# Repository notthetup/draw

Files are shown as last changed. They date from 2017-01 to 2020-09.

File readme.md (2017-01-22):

Draw
===

INA260 based voltage and current __draw__ measurement board.

This is a INA260 based board for measuring voltage and current draw (with builtin shunt) and output over USB (CDC).

## Components

- [INA260](http://www.ti.com/lit/ds/symlink/ina260.pdf) - Current Sensing Amplifier With Integrated Shunt.
- [EFM32HG309](https://www.silabs.com/Support%20Documents/TechnicalDocs/EFM32HG309.pdf) - Simple Microcontroller for I2C -> USB conversion.
- [TPD4E002](http://www.ti.com/lit/ds/symlink/tpd4e002.pdf) - ESD Protection IC

## Resources

- [USB-CDC Example from SiLabs](https://github.com/SiliconLabs/Gecko_SDK/tree/master/hardware/kit/SLSTK3400A_EFM32HG/examples/usbdcdc)
- [TOMU](https://github.com/im-tomu/)
- [TOMU Example](https://github.com/im-tomu/tomu-samples/tree/master/efm32hg-blinky-usb)

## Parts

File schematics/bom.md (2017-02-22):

| Ref | Value | Type | Model | Ord/Rcd | | | | |
|-----|---|---|---|---|---|---|---|---|
| R1  | 0R | device | R_Small |  50/50  | | | | |
| R2  | 0R | device | R_Small |  50/50  | | | | |
| R3  | 0R | device | R_Small |  50/50  | | | | |
| R4  | 0R | device | R_Small |  50/50  | | | | |
| R5  | 0R | device | R_Small |  50/50  | | | | |
| R10 | 0R | device | R_Small |  50/50  | | | | |
| R12 | 0R | device | R_Small |  50/50  | | | | |
| R13 | 1K | device | R_Small |  50/50  | | | | |
| R14 | 1K | device | R_Small |  50/50  | | | | |
| R15 | 1K | device | R_Small |  50/50  | | | | |
| C3  | 1uF | device | C_Small |  60/60  | | | | |
| C2  | 1uF | device | C_Small |  60/60  | | | | |
| C5  | 1uF | device | C_Small |  60/60  | | | | |
| R6  | 15R | device | R_Small |  50/50  | | | | |
| R7  | 15R | device | R_Small |  50/50  | | | | |
| C1  | 4.7uF | device | C_Small |  10/10  | | | | |
| C1  | 4.7uF | device | C_Small |  10/10  | | | | |
| C4  | 0.1uF | device | C_Small |  50/50  | | | | |
| C6  | 1nF | device | C_Small |  50/50  | | | | |
| R8  | 100R | device | R_Small |  50/50  | | | | |
| L1  | 100R | device | Ferrite_Bead_Small |  10/10  | | | | |
| U1  | EFM32HG309 | draw | EFM32HG309 |  3/3 | | | | |
| U2  | TPD4E002 | draw | TPD4E002 |  10/10  | | | | |
| U3  | INA260 | draw | INA260 |  5/5 | | | | |
| P1  | I2C Conn | conn | CONN_01X04 | InHouse | | | | |
| P2  | UART Conn  | conn | CONN_01X04 | InHouse | | | | |
| P3  | Debug Conn | conn | CONN_01X04 | InHouse | | | | |
| P6  | Power_OUT  | conn | CONN_01X02 |  5/5 | | | | |
| P5  | Power_IN | conn | CONN_01X02 |  5/5 | | | | |
| P4  | USB_OTG | conn | USB_OTG |  5/5 | | | | |
| SW1 | SW_Push | switches | SW_Push |  10/10  | | | | |
| D1  | LED | device | LED |  10/10  | | | | |
| R9  | 0R_NP | device | R_Small |  NP | | | | |
| R11 | 0R_NP | device | R_Small |  NP | | | | |

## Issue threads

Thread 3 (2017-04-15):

Fix button footprint

notthetup, 2017-04-15:

notthetup, 2017-04-15:
Fixed in 5bd433279bf20e20d566c2123c99ecc8e3fc2ee7

notthetup, 2018-02-08:
Move to a press down button.

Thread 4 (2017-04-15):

Remove keepout for high current connectors

notthetup, 2017-04-15:
Remove heat relief and pin keepout from

1. Terminal blocks.
2. 1st 3 pins of INA260.

notthetup, 2017-04-15:
Fixed in ede29ea973610703563ed074c830674fd9ce4f38

Closed 2017-04-15.

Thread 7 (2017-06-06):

Remove mounting holes for rubber feet

notthetup, 2017-06-06:
Since the board is most commonly going to be used along with a laptop, using rubber feet glued onto the bottom makes more sense than wasting space for mounting holes.

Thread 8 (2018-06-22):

Move to a through hole USB adapter

notthetup, 2018-06-22:
Heard it on TheAmpHour “surface mount USB connector, not even once”.

https://overcast.fm/+kInNOyMM/55:00

notthetup, 2019-08-19:
Cuttent USB Connector is already through hole.

Closed 2019-08-19.

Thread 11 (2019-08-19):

Add a button to enter bootloader

notthetup, 2019-08-19:
> Bootloader is forced by a short between CAP1A (PC1) and CAP0B (PE12)

Closed 2019-08-19.

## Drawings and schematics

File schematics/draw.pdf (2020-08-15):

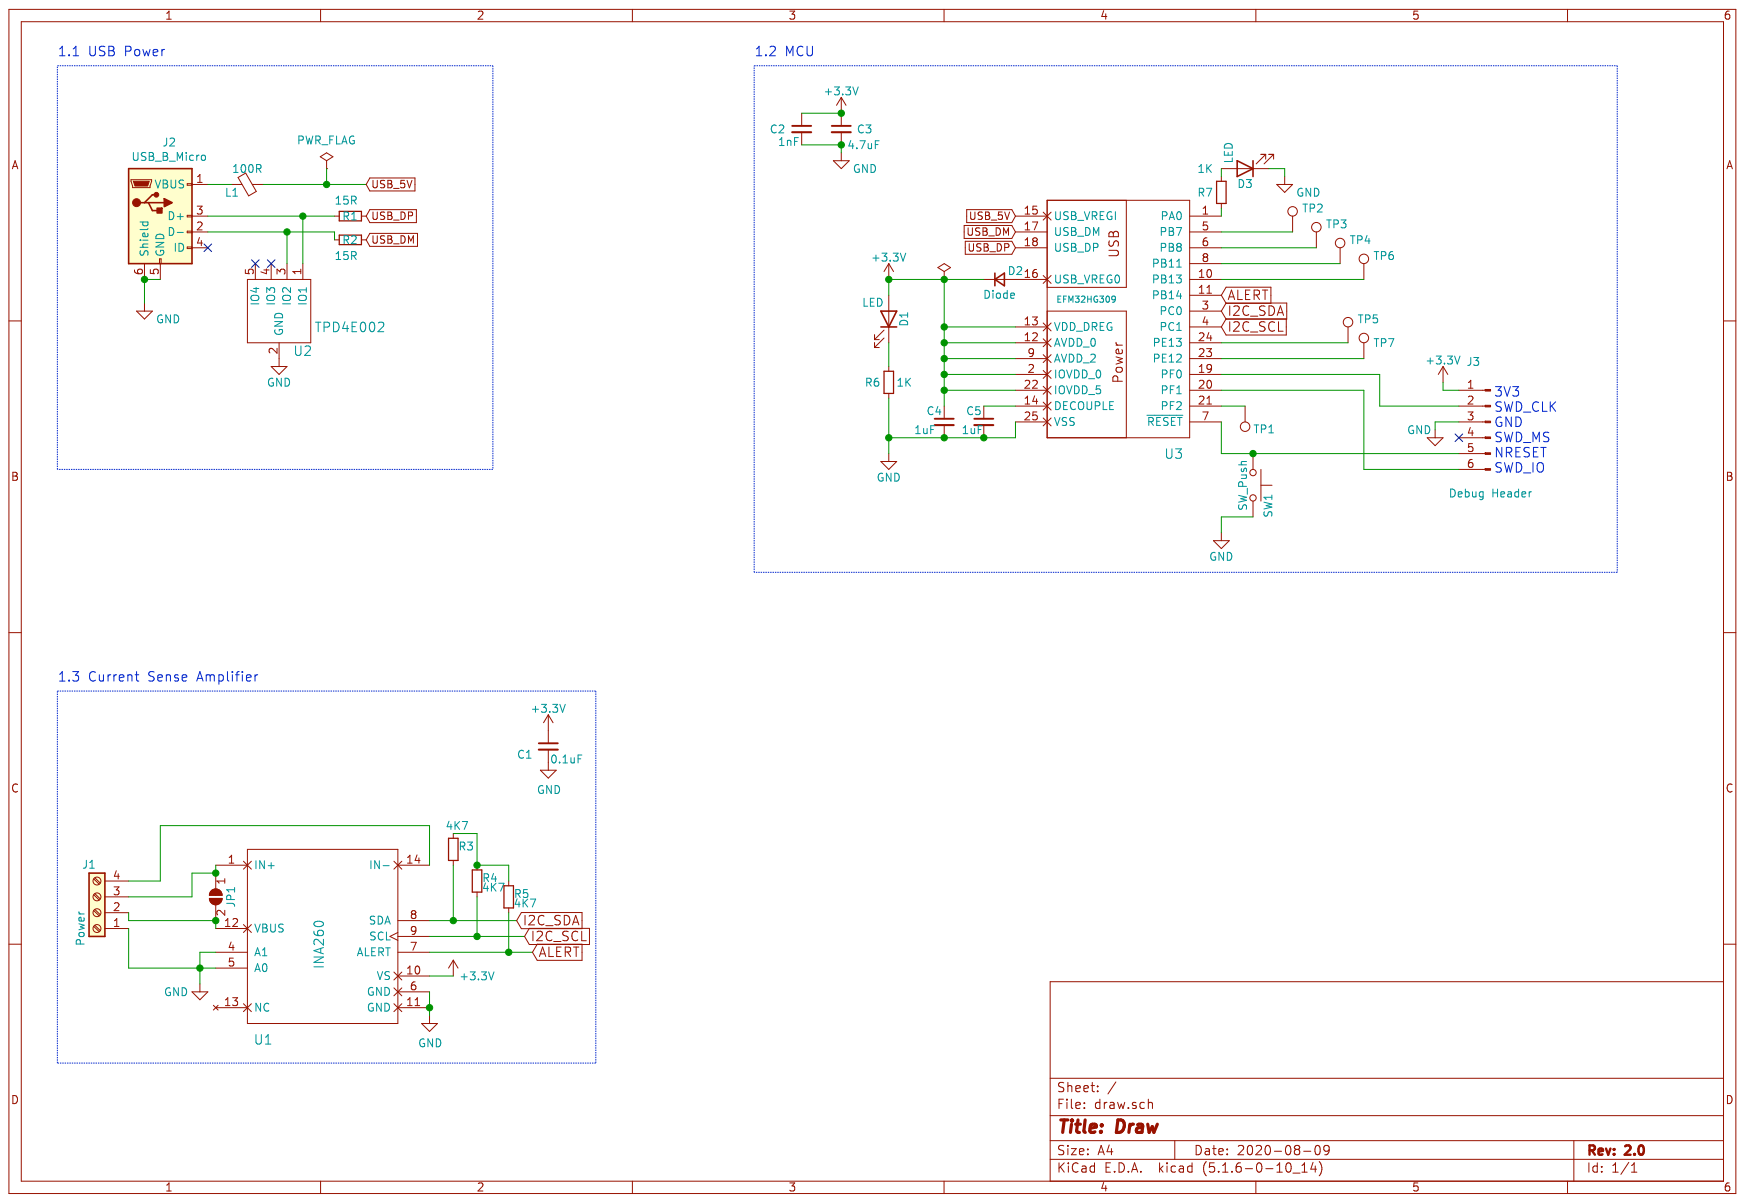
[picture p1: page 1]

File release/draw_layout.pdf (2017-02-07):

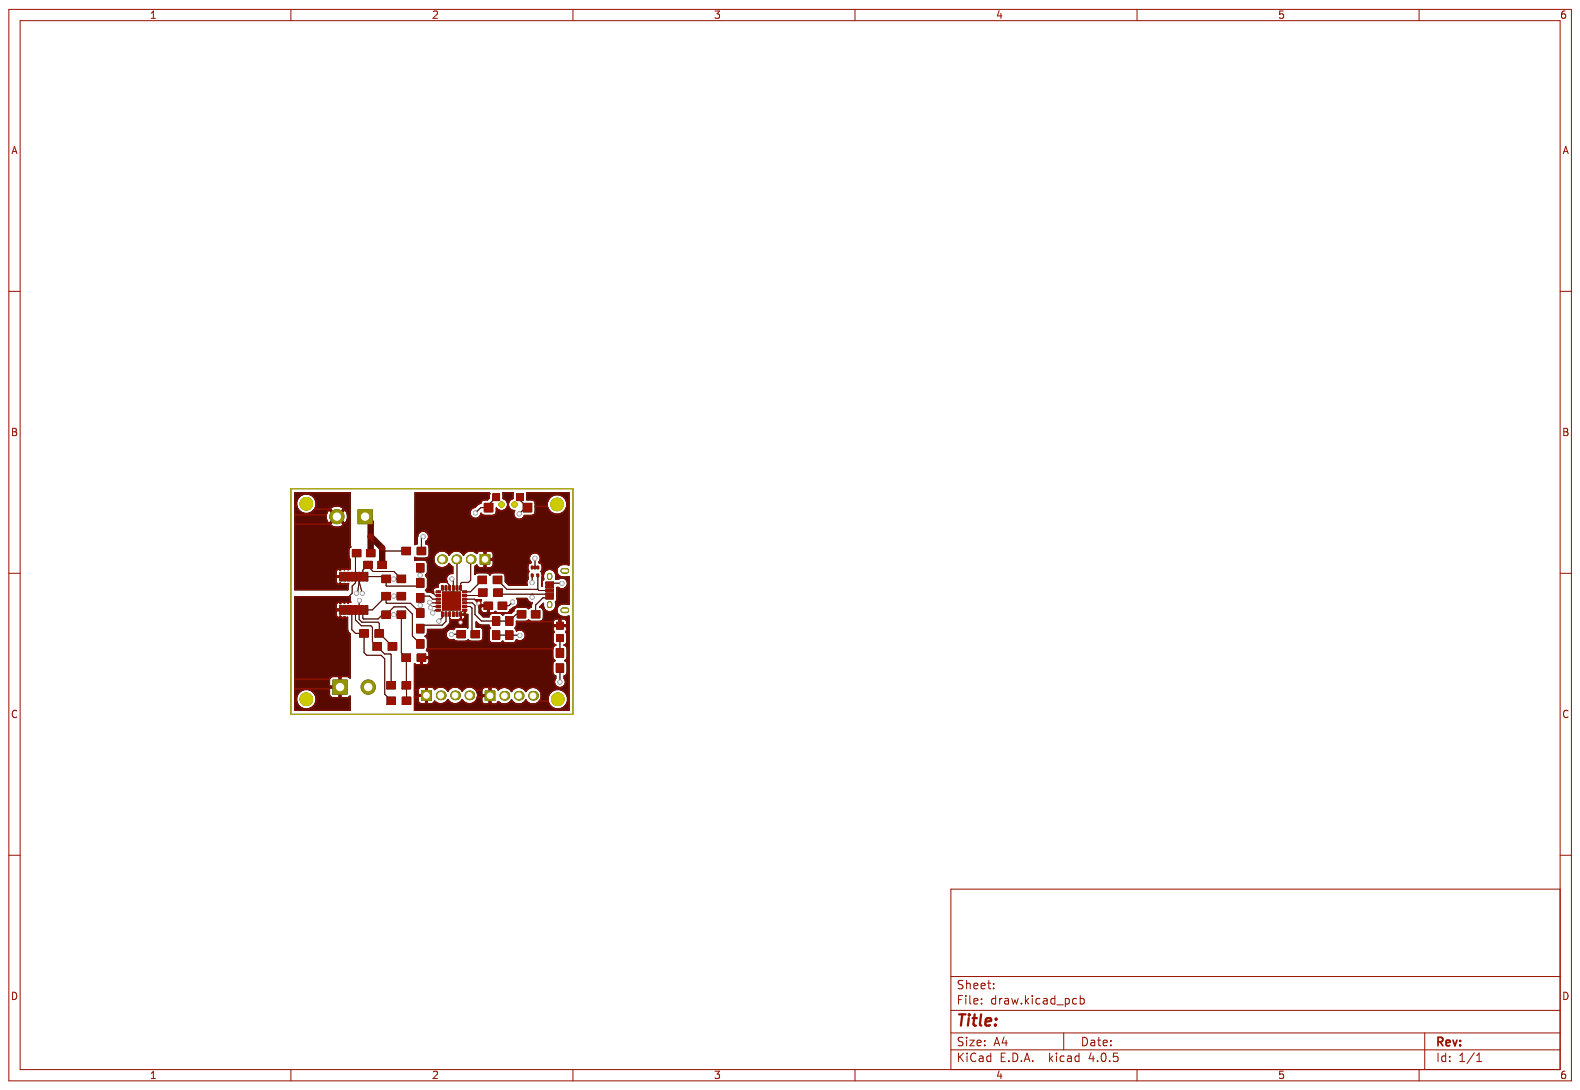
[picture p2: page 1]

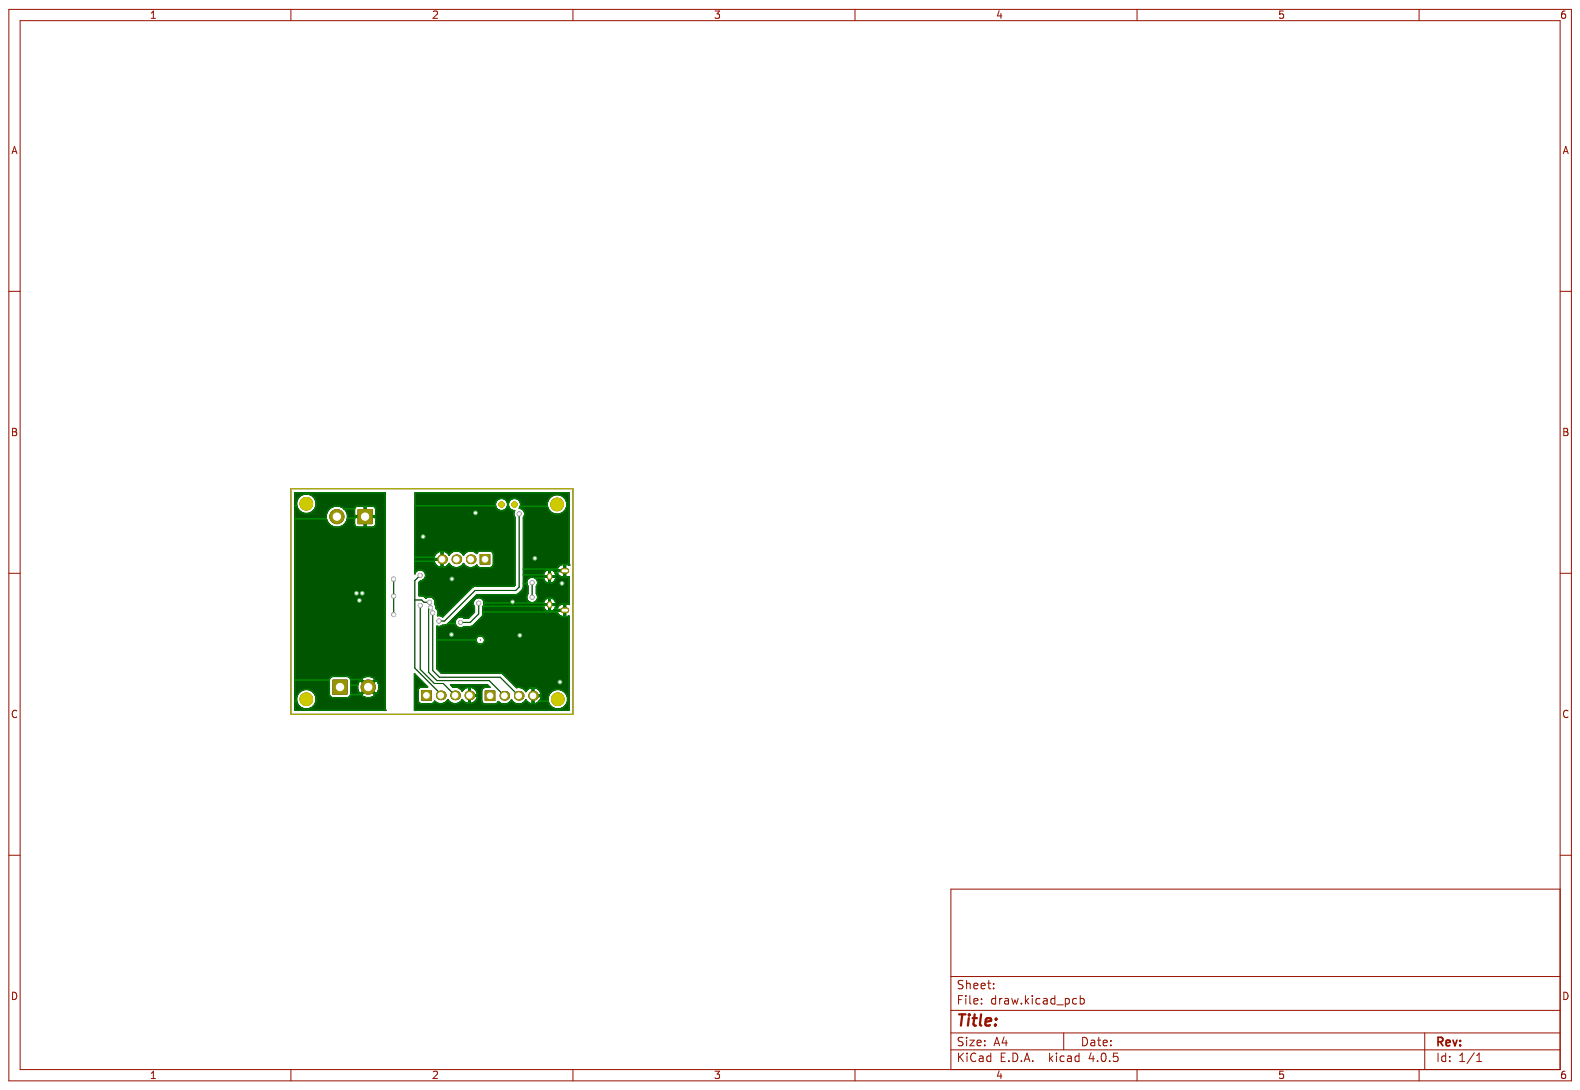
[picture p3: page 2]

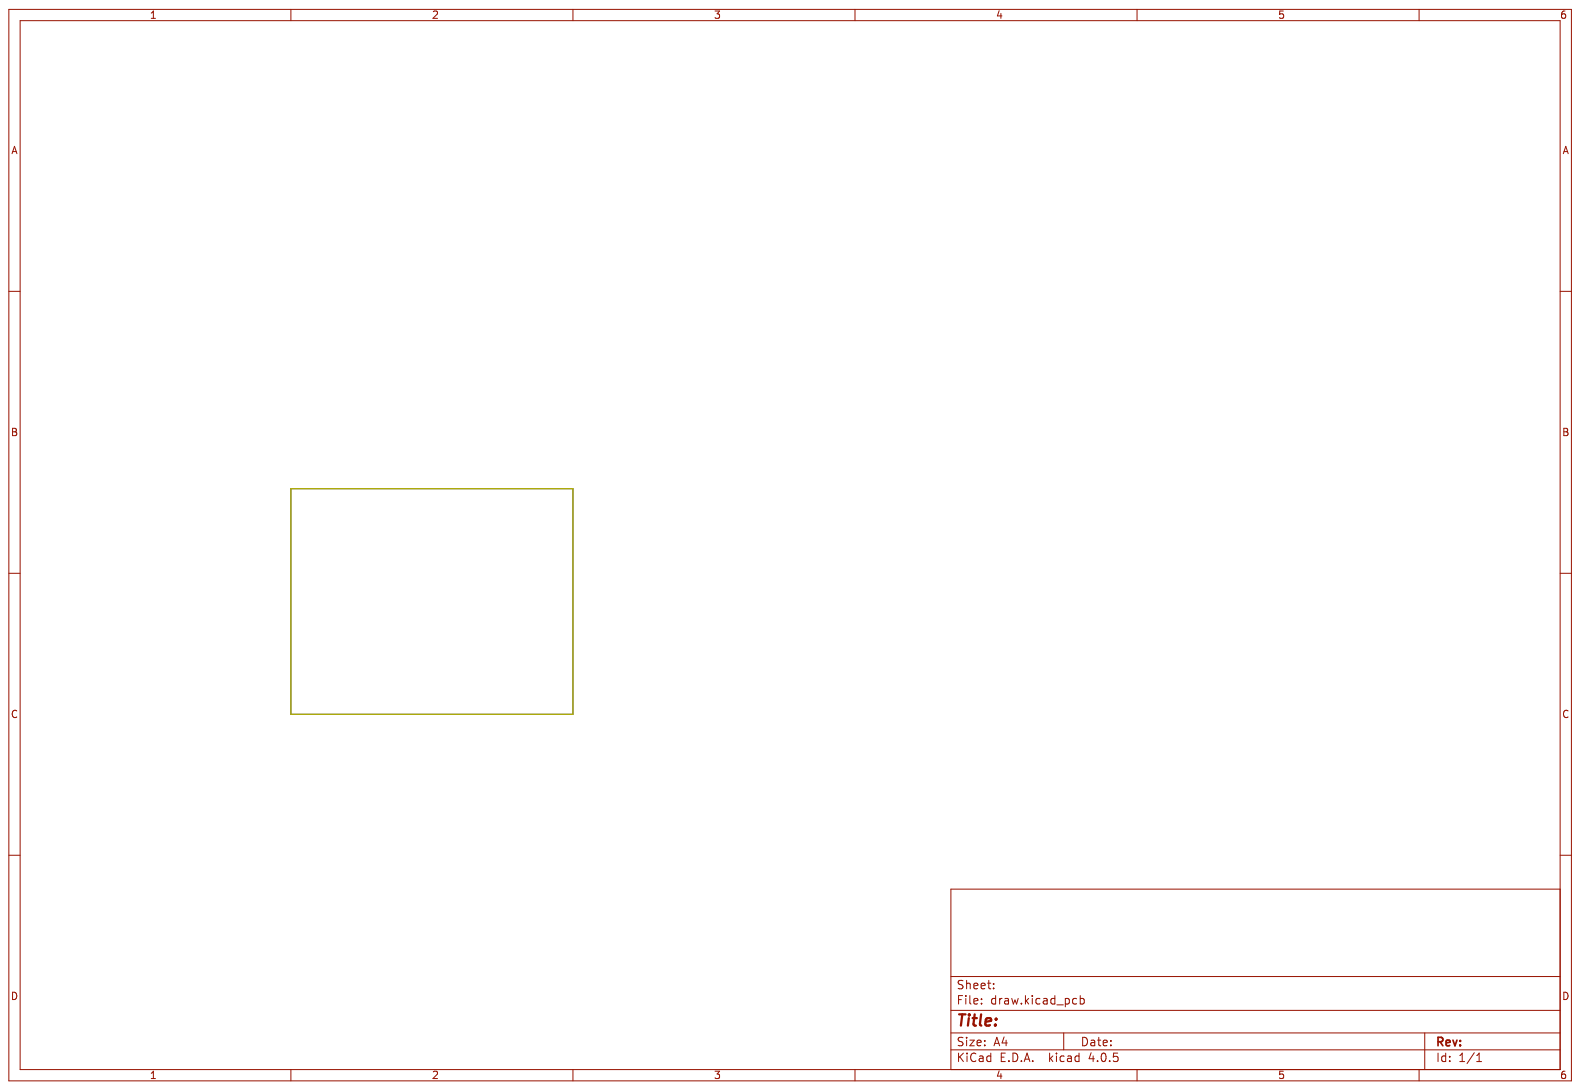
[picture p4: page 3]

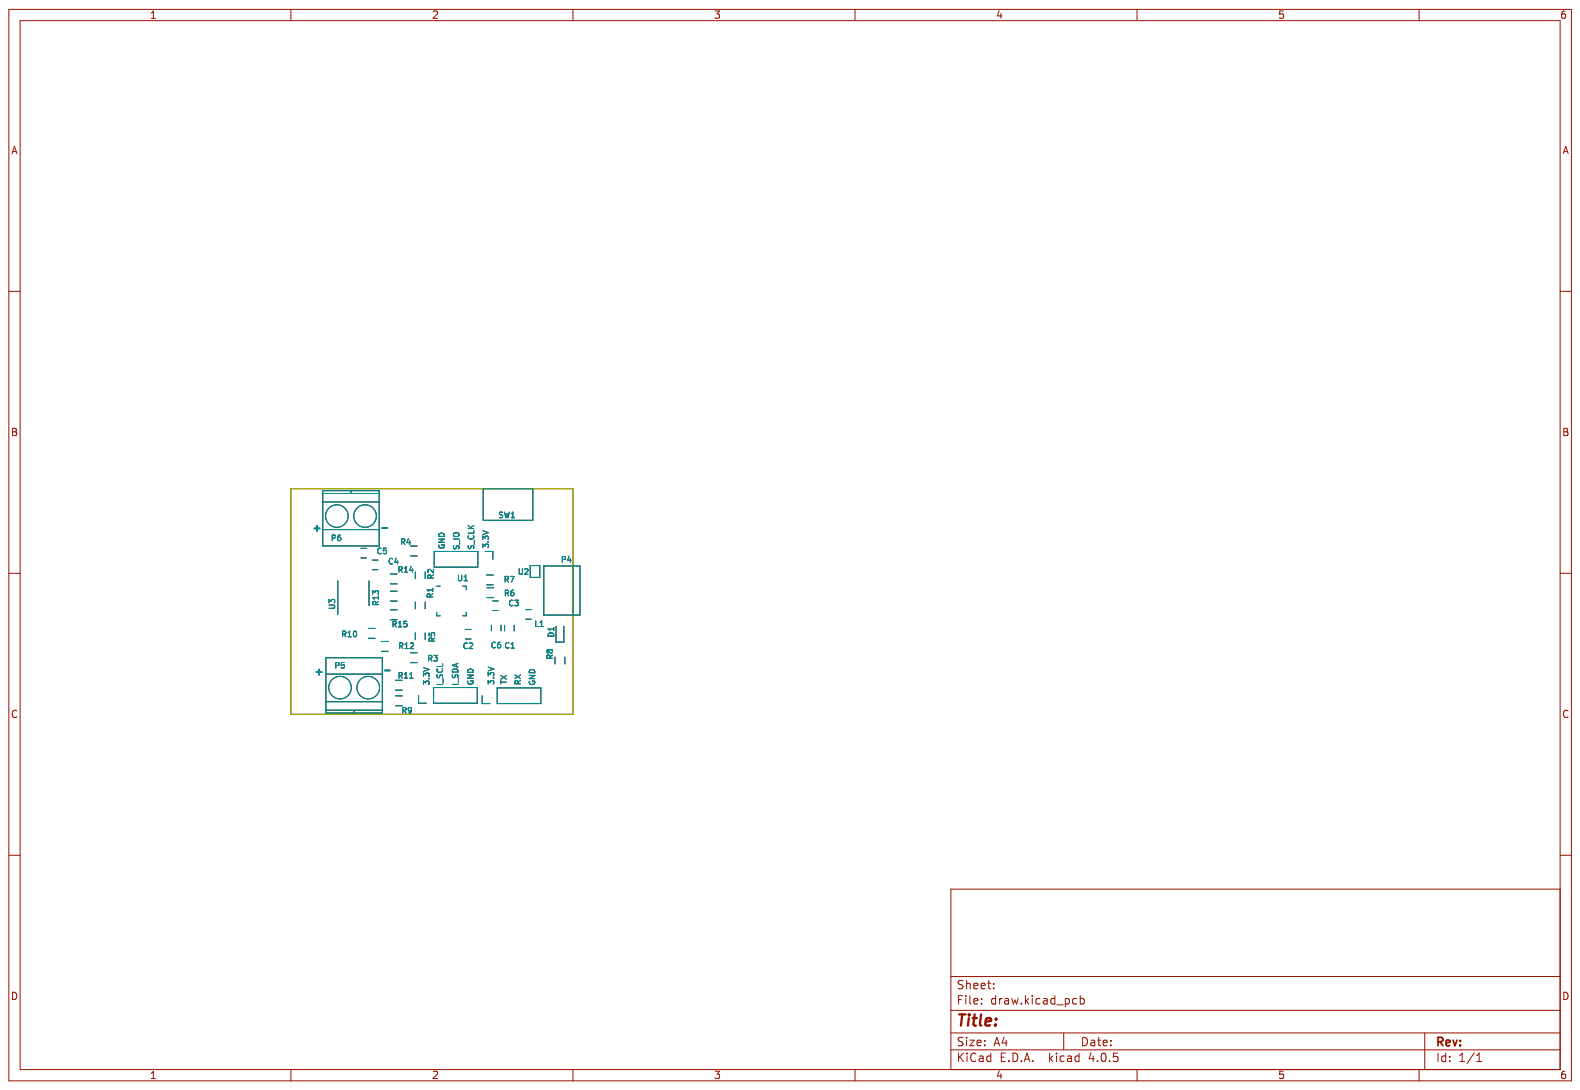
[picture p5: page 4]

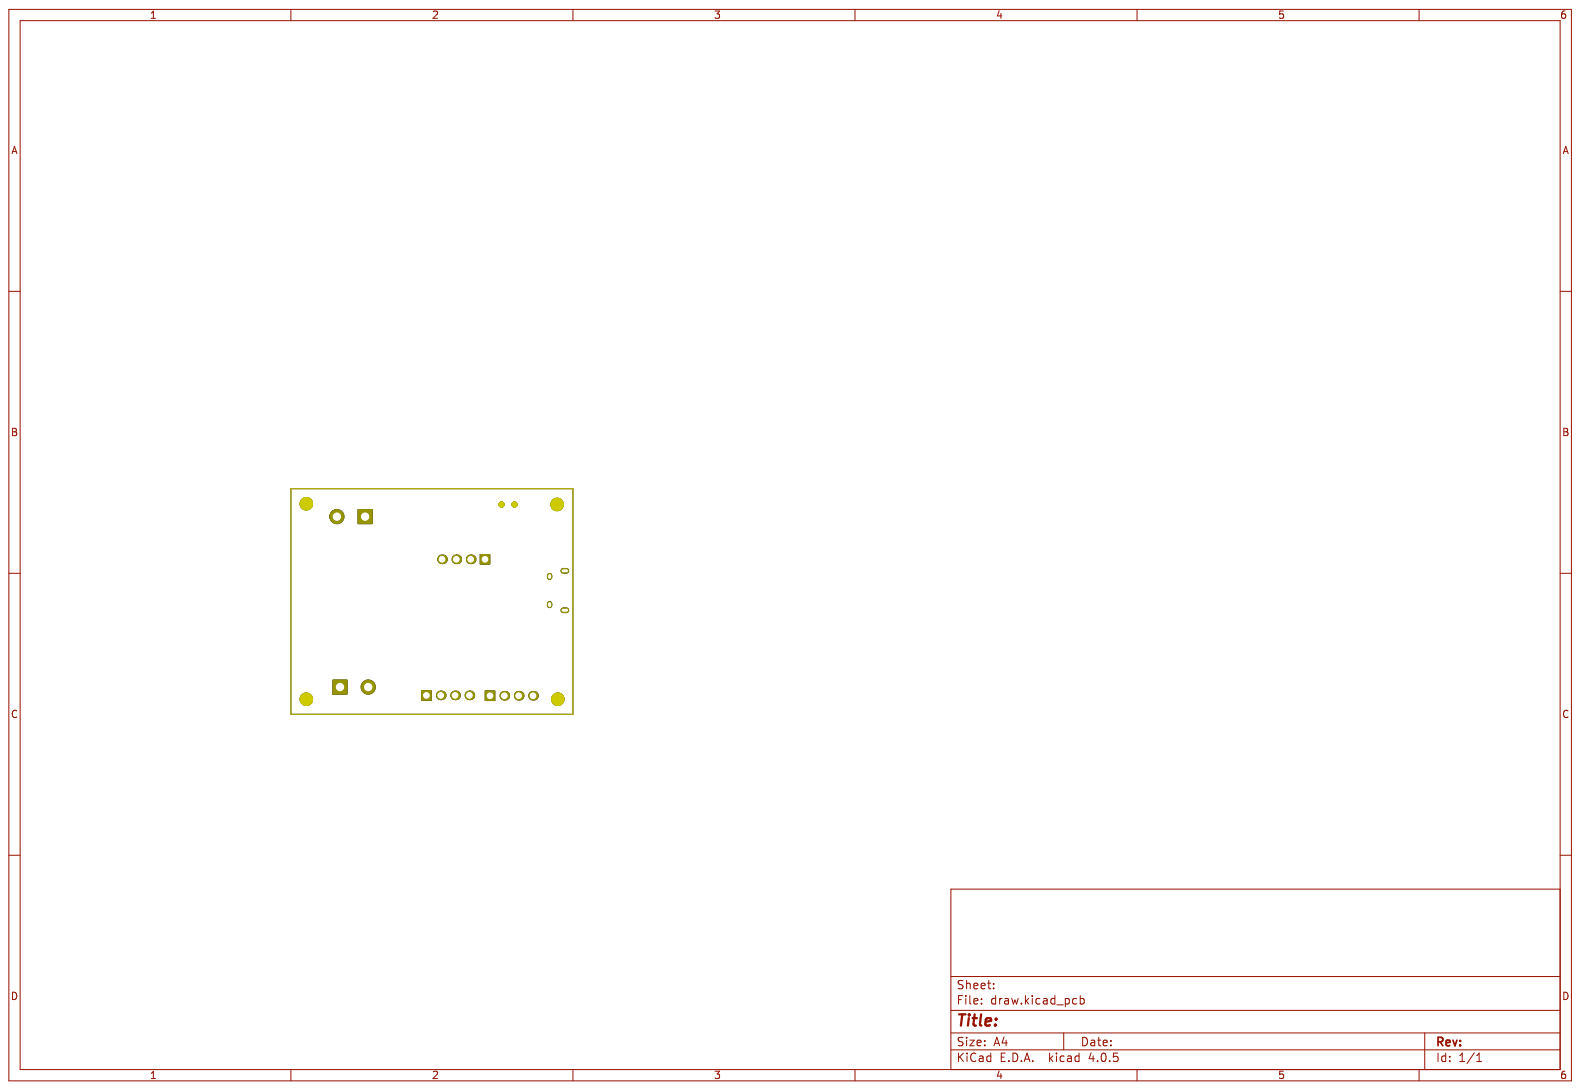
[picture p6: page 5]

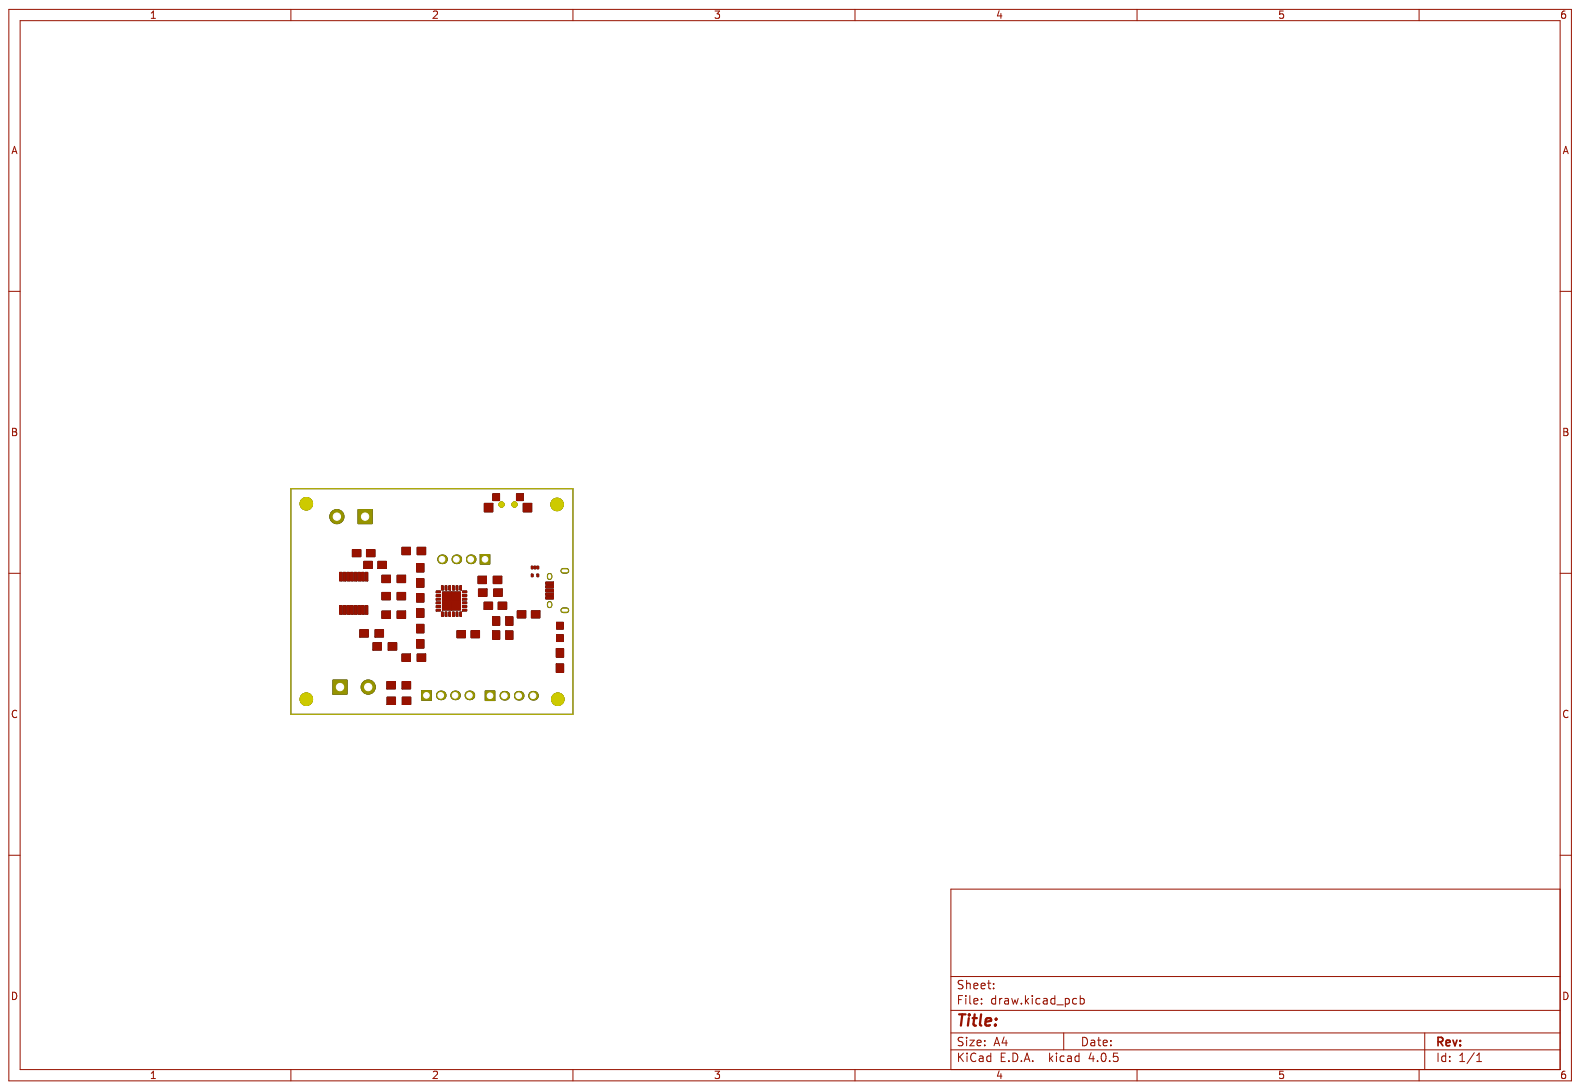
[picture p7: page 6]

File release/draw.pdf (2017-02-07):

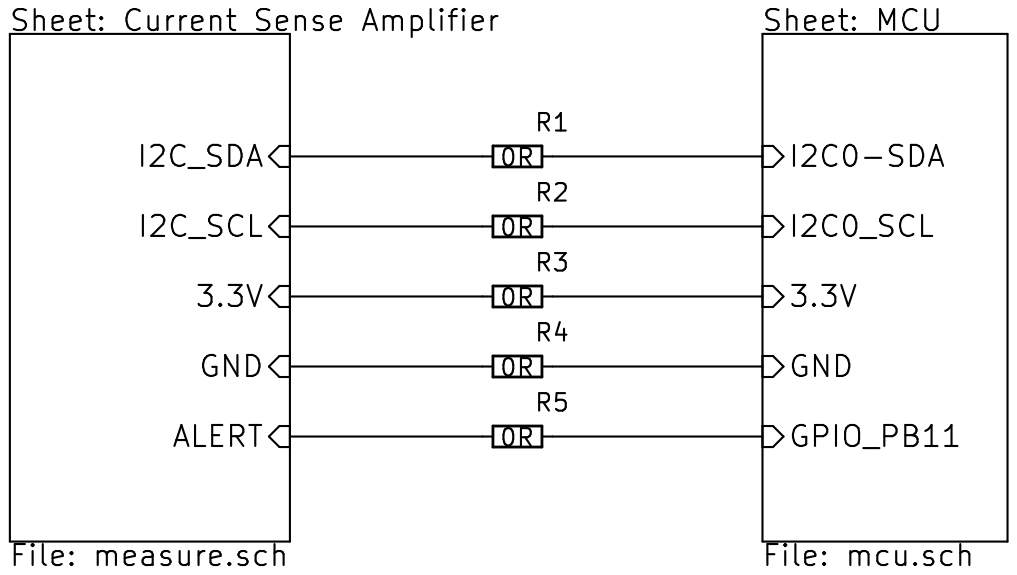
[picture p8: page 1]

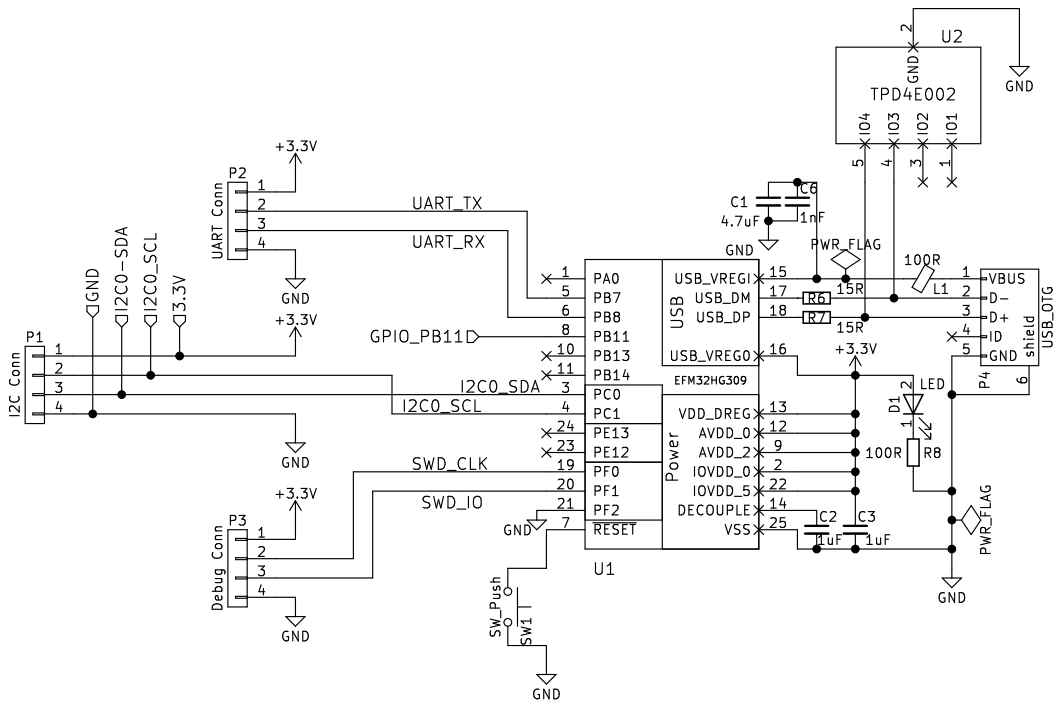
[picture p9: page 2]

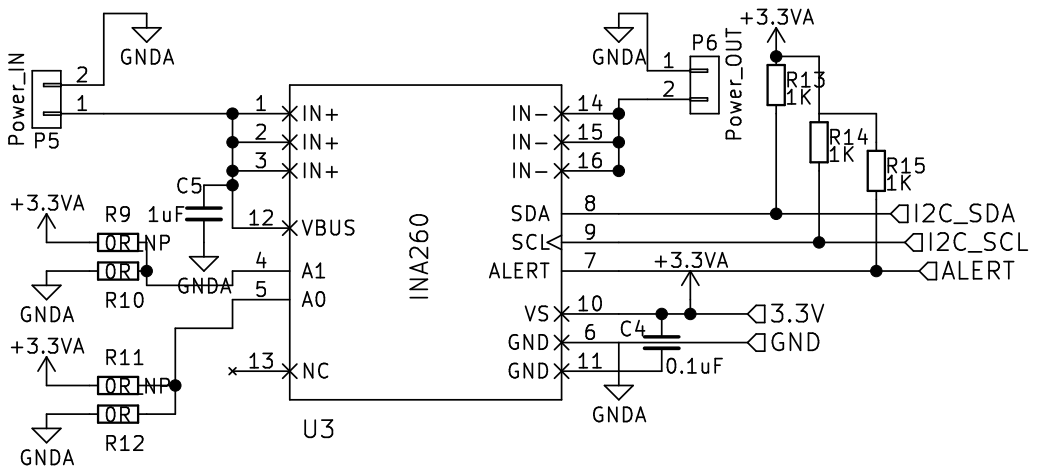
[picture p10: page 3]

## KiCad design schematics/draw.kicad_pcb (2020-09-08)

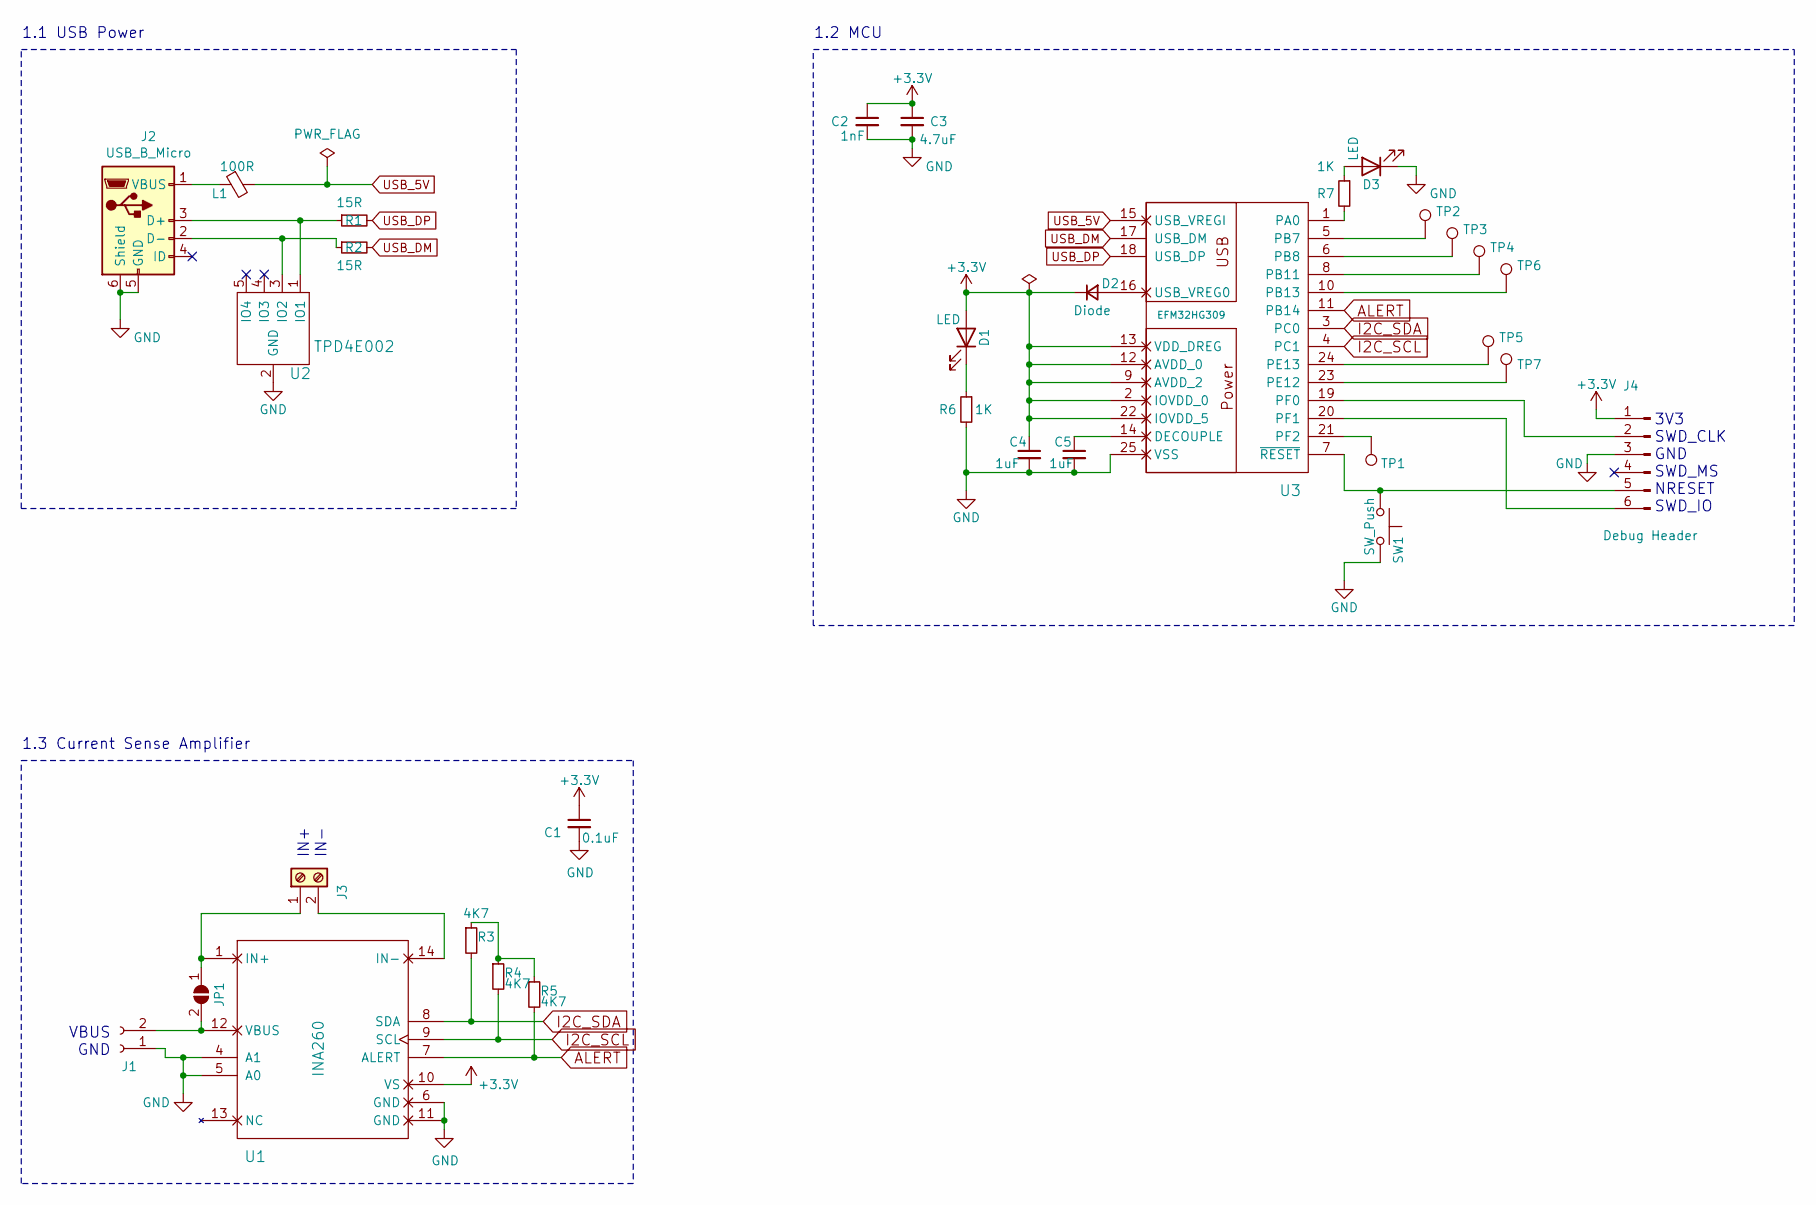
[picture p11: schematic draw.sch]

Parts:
C1: 0.1uF; C_0805_2012Metric_Pad1.15x1.40mm_HandSolder
C2: 1nF; C_0805_2012Metric_Pad1.15x1.40mm_HandSolder
C3: 4.7uF; C_0805_2012Metric_Pad1.15x1.40mm_HandSolder
C4, C5: 1uF; C_0805_2012Metric_Pad1.15x1.40mm_HandSolder
D1, D3: LED; LED_0805_2012Metric_Pad1.15x1.40mm_HandSolder
D2: Diode; D_0805_2012Metric_Pad1.15x1.40mm_HandSolder
J1: Conn_01x02_Female; PinHeader_1x02_P1.00mm_Vertical
J2: USB_B_Micro; USB_Micro-B_Amphenol_10103594-0001LF_Horizontal
J3: Screw_Terminal_01x02; TerminalBlock_MetzConnect_Type086_RT03402HBLC_1x02_P3.81mm_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
J4: Debug Header; PinSocket_1x06_P2.54mm_Vertical
JP1: Jumper; SolderJumper-2_P1.3mm_Open_RoundedPad1.0x1.5mm
L1: 100R; L_0805_2012Metric_Pad1.15x1.40mm_HandSolder
R1, R2: 15R; R_0805_2012Metric_Pad1.15x1.40mm_HandSolder
R3, R4, R5: 4K7; R_0805_2012Metric_Pad1.15x1.40mm_HandSolder
R6, R7: 1K; R_0805_2012Metric_Pad1.15x1.40mm_HandSolder
SW1: SW_Push; Tact
TP1, TP2, TP3, TP4, TP5, TP6, TP7: TestPoint; TestPoint_Pad_2.0x2.0mm
U1: INA260; TSSOP-16_4.4x5mm_P0.65mm
U2: TPD4E002; SOT-553
U3: EFM32HG309; QFN-24-1EP_5x5mm_P0.65mm_EP3.6x3.6mm

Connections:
+3V3: C1.1, C2.1, C3.1, C4.1, D1.2 (A), D2.1 (K), J4.1, U1.10 (VS), U3.2 (IOVDD_0), U3.9 (AVDD_2), U3.12 (AVDD_0), U3.13 (VDD_DREG), U3.22 (IOVDD_5)
ALERT: R5.2, U1.7 (ALERT), U3.11 (PB14)
GND: C1.2, C2.2, C3.2, C4.2, C5.2, D3.1 (K), J1.1, J2.5 (GND), J2.6 (Shield), J4.3, R6.2, SW1.2, U1.4 (A1), U1.5 (A0), U1.6 (GND), U1.11 (GND), U2.2 (GND), U3.25 (VSS)
I2C_SCL: R4.2, U1.9 (SCL), U3.4 (PC1)
I2C_SDA: R3.2, U1.8 (SDA), U3.3 (PC0)
unnamed: C5.1, U3.14 (DECOUPLE)
unnamed: D1.1 (K), R6.1
unnamed: D2.2 (A), U3.16 (USB_VREG0)
unnamed: D3.2 (A), R7.1
unnamed: J1.2, JP1.2 (B), U1.12 (VBUS)
unnamed: J2.1 (VBUS), L1.1
unnamed: J2.2 (D-), R2.1, U2.3 (IO2)
unnamed: J2.3 (D+), R1.1, U2.1 (IO1)
unnamed: J3.1, JP1.1 (A), U1.1 (IN+), U1.2 (IN+), U1.3 (IN+)
unnamed: J3.2, U1.14 (IN-), U1.15 (IN-), U1.16 (IN-)
unnamed: J4.2, U3.19 (PF0)
unnamed: J4.5, SW1.1, U3.7 (~RESET)
unnamed: J4.6, U3.20 (PF1)
unnamed: R3.1, R4.1, R5.1
unnamed: R7.2, U3.1 (PA0)
unnamed: TP1.1, U3.21 (PF2)
unnamed: TP2.1, U3.5 (PB7)
unnamed: TP3.1, U3.6 (PB8)
unnamed: TP4.1, U3.8 (PB11)
unnamed: TP5.1, U3.24 (PE13)
unnamed: TP6.1, U3.10 (PB13)
unnamed: TP7.1, U3.23 (PE12)
USB_5V: L1.2, U3.15 (USB_VREGI)
USB_DM: R2.2, U3.17 (USB_DM)
USB_DP: R1.2, U3.18 (USB_DP)

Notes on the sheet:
3V3 SWD_CLK GND SWD_MS NRESET SWD_IO
1.1 USB Power
1.2 MCU
1.3 Current Sense Amplifier
IN+ IN-
VBUS GND

Board: 2 copper layers, 32 parts (0 on the bottom side), 30 nets, no tracks yet.

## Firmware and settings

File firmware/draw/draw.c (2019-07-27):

/*
 * This file is part of the libopencm3 project.
 *
 * Copyright (C) 2010 Gareth McMullin <gareth@blacksphere.co.nz>
 * Copyright (C) 2015 Piotr Esden-Tempski <piotr@esden.net>
 * Copyright (C) 2018 Seb Holzapfel <schnommus@gmail.com>
 *
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
 * You should have received a copy of the GNU Lesser General Public License
 * along with this library.  If not, see <http://www.gnu.org/licenses/>.
 */

/**
 * \addtogroup Examples
 *
 * This example implements a USB CDC-ACM device (aka Virtual Serial Port)
 * to demonstrate the use of the USB device stack.
 *
 * When data is recieved, it will toggle the green LED and echo the data.
 * The red LED is toggled constantly and a string is sent over USB every
 * time the LED changes state as a heartbeat.
 */

#include <libopencm3/cm3/common.h>
#include <libopencm3/cm3/vector.h>
#include <libopencm3/cm3/scb.h>
#include <libopencm3/cm3/nvic.h>
#include <libopencm3/usb/usbd.h>
#include <libopencm3/usb/cdc.h>
#include <libopencm3/efm32/wdog.h>
#include <libopencm3/efm32/gpio.h>
#include <libopencm3/efm32/cmu.h>

#include <stdbool.h>
#include <stdio.h>
#include <string.h>

/* Default AHB (core clock) frequency of Tomu board */
#define AHB_FREQUENCY 14000000

#define LED_GREEN_PORT GPIOA
#define LED_GREEN_PIN  GPIO0
#define LED_RED_PORT   GPIOB
#define LED_RED_PIN    GPIO7

#define VENDOR_ID                 0x1209    /* pid.code */
#define PRODUCT_ID                0x70b1    /* Assigned to Tomu project */
#define DEVICE_VER                0x0101    /* Program version */

bool g_usbd_is_connected = false;
usbd_device *g_usbd_dev = 0;

static const struct usb_device_descriptor dev = {
	.bLength = USB_DT_DEVICE_SIZE,
	.bDescriptorType = USB_DT_DEVICE,
	.bcdUSB = 0x0200,
	.bDeviceClass = USB_CLASS_CDC,
	.bDeviceSubClass = 0,
	.bDeviceProtocol = 0,
	.bMaxPacketSize0 = 64,
	.idVendor = VENDOR_ID,
	.idProduct = PRODUCT_ID,
	.bcdDevice = DEVICE_VER,
	.iManufacturer = 1,
	.iProduct = 2,
	.iSerialNumber = 3,
	.bNumConfigurations = 1,
};

/*
 * This notification endpoint isn't implemented. According to CDC spec its
 * optional, but its absence causes a NULL pointer dereference in Linux
 * cdc_acm driver.
 */
static const struct usb_endpoint_descriptor comm_endp[] = {{
	.bLength = USB_DT_ENDPOINT_SIZE,
	.bDescriptorType = USB_DT_ENDPOINT,
	.bEndpointAddress = 0x83,
	.bmAttributes = USB_ENDPOINT_ATTR_INTERRUPT,
	.wMaxPacketSize = 16,
	.bInterval = 255,
}};

static const struct usb_endpoint_descriptor data_endp[] = {{
	.bLength = USB_DT_ENDPOINT_SIZE,
	.bDescriptorType = USB_DT_ENDPOINT,
	.bEndpointAddress = 0x01,
	.bmAttributes = USB_ENDPOINT_ATTR_BULK,
	.wMaxPacketSize = 64,
	.bInterval = 1,
}, {
	.bLength = USB_DT_ENDPOINT_SIZE,
	.bDescriptorType = USB_DT_ENDPOINT,
	.bEndpointAddress = 0x82,
	.bmAttributes = USB_ENDPOINT_ATTR_BULK,
	.wMaxPacketSize = 64,
	.bInterval = 1,
}};

static const struct {
	struct usb_cdc_header_descriptor header;
	struct usb_cdc_call_management_descriptor call_mgmt;
	struct usb_cdc_acm_descriptor acm;
	struct usb_cdc_union_descriptor cdc_union;
} __attribute__((packed)) cdcacm_functional_descriptors = {
	.header = {
		.bFunctionLength = sizeof(struct usb_cdc_header_descriptor),
		.bDescriptorType = CS_INTERFACE,
		.bDescriptorSubtype = USB_CDC_TYPE_HEADER,
		.bcdCDC = 0x0110,
	},
	.call_mgmt = {
		.bFunctionLength =
			sizeof(struct usb_cdc_call_management_descriptor),
		.bDescriptorType = CS_INTERFACE,
		.bDescriptorSubtype = USB_CDC_TYPE_CALL_MANAGEMENT,
		.bmCapabilities = 0,
		.bDataInterface = 1,
	},
	.acm = {
		.bFunctionLength = sizeof(struct usb_cdc_acm_descriptor),
		.bDescriptorType = CS_INTERFACE,
		.bDescriptorSubtype = USB_CDC_TYPE_ACM,
		.bmCapabilities = 0,
	},
	.cdc_union = {
		.bFunctionLength = sizeof(struct usb_cdc_union_descriptor),
		.bDescriptorType = CS_INTERFACE,
		.bDescriptorSubtype = USB_CDC_TYPE_UNION,
		.bControlInterface = 0,
		.bSubordinateInterface0 = 1,
	 }
};

static const struct usb_interface_descriptor comm_iface[] = {{
	.bLength = USB_DT_INTERFACE_SIZE,
	.bDescriptorType = USB_DT_INTERFACE,
	.bInterfaceNumber = 0,
	.bAlternateSetting = 0,
	.bNumEndpoints = 1,
	.bInterfaceClass = USB_CLASS_CDC,
	.bInterfaceSubClass = USB_CDC_SUBCLASS_ACM,
	.bInterfaceProtocol = USB_CDC_PROTOCOL_AT,
	.iInterface = 0,

	.endpoint = comm_endp,

	.extra = &cdcacm_functional_descriptors,
	.extralen = sizeof(cdcacm_functional_descriptors)
}};

static const struct usb_interface_descriptor data_iface[] = {{
	.bLength = USB_DT_INTERFACE_SIZE,
	.bDescriptorType = USB_DT_INTERFACE,
	.bInterfaceNumber = 1,
	.bAlternateSetting = 0,
	.bNumEndpoints = 2,
	.bInterfaceClass = USB_CLASS_DATA,
	.bInterfaceSubClass = 0,
	.bInterfaceProtocol = 0,
	.iInterface = 0,

	.endpoint = data_endp,
}};

static const struct usb_interface ifaces[] = {{
	.num_altsetting = 1,
	.altsetting = comm_iface,
}, {
	.num_altsetting = 1,
	.altsetting = data_iface,
}};

static const struct usb_config_descriptor config = {
	.bLength = USB_DT_CONFIGURATION_SIZE,
	.bDescriptorType = USB_DT_CONFIGURATION,
	.wTotalLength = 0,
	.bNumInterfaces = 2,
	.bConfigurationValue = 1,
	.iConfiguration = 0,
	.bmAttributes = 0x80,
	.bMaxPower = 0x32,

	.interface = ifaces,
};

static const char *usb_strings[] = {
	"Tomu",
	"CDC-ACM Demo",
	"DEMO",
};

/* Buffer to be used for control requests. */
uint8_t usbd_control_buffer[128];

static enum usbd_request_return_codes cdcacm_control_request(usbd_device *usbd_dev, struct usb_setup_data *req, uint8_t **buf,
		uint16_t *len, void (**complete)(usbd_device *usbd_dev, struct usb_setup_data *req))
{
	(void)complete;
	(void)buf;
	(void)usbd_dev;

	switch(req->bRequest) {
	case USB_CDC_REQ_SET_CONTROL_LINE_STATE: {
        g_usbd_is_connected = req->wValue & 1; /* Check RTS bit */
		return USBD_REQ_HANDLED;
		}
	case USB_CDC_REQ_SET_LINE_CODING:
		if(*len < sizeof(struct usb_cdc_line_coding))
			return 0;

		return USBD_REQ_HANDLED;
	}
	return 0;
}

/* Simple callback that echoes whatever is sent */
static void cdcacm_data_rx_cb(usbd_device *usbd_dev, uint8_t ep)
{
	(void)ep;

    /* We got some data, toggle the green LED */
    gpio_toggle(LED_GREEN_PORT, LED_GREEN_PIN);

	char buf[64];
	int len = usbd_ep_read_packet(usbd_dev, 0x01, buf, 64);

	if (len) {
		usbd_ep_write_packet(usbd_dev, 0x82, buf, len);
		buf[len] = 0;
	}
}

static void cdcacm_set_config(usbd_device *usbd_dev, uint16_t wValue)
{
	(void)wValue;

	usbd_ep_setup(usbd_dev, 0x01, USB_ENDPOINT_ATTR_BULK, 64, cdcacm_data_rx_cb);
	usbd_ep_setup(usbd_dev, 0x82, USB_ENDPOINT_ATTR_BULK, 64, 0);
	usbd_ep_setup(usbd_dev, 0x83, USB_ENDPOINT_ATTR_INTERRUPT, 16, 0);

	usbd_register_control_callback(
				usbd_dev,
				USB_REQ_TYPE_CLASS | USB_REQ_TYPE_INTERFACE,
				USB_REQ_TYPE_TYPE | USB_REQ_TYPE_RECIPIENT,
				cdcacm_control_request);
}

static void usb_puts(char *s) {
    if(g_usbd_is_connected) {
        usbd_ep_write_packet(g_usbd_dev, 0x82, s, strnlen(s, 64));
    }
}

void usb_isr(void)
{
    usbd_poll(g_usbd_dev);
}

void hard_fault_handler(void)
{
    while(1);
}

int main(void)
{
    int i;

    /* Make sure the vector table is relocated correctly (after the Tomu bootloader) */
    SCB_VTOR = 0x4000;

    /* Disable the watchdog that the bootloader started. */
    WDOG_CTRL = 0;

    /* GPIO peripheral clock is necessary for us to set up the GPIO pins as outputs */
    cmu_periph_clock_enable(CMU_GPIO);

    /* Set up both LEDs as outputs */
    gpio_mode_setup(LED_RED_PORT, GPIO_MODE_WIRED_AND, LED_RED_PIN);
    gpio_mode_setup(LED_GREEN_PORT, GPIO_MODE_WIRED_AND, LED_GREEN_PIN);

    /* Configure the USB core & stack */
	g_usbd_dev = usbd_init(&efm32hg_usb_driver, &dev, &config, usb_strings, 3, usbd_control_buffer, sizeof(usbd_control_buffer));
	usbd_register_set_config_callback(g_usbd_dev, cdcacm_set_config);

    /* Enable USB IRQs */
	nvic_enable_irq(NVIC_USB_IRQ);

    while(1) {
        usb_puts("toggling LED\n\r");
        gpio_toggle(LED_RED_PORT, LED_RED_PIN);
        for(i = 0; i != 500000; ++i)
			__asm__("nop");
    }
}

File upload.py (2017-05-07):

#! /usr/bin/env python

import logging
import serial
from xmodem import XMODEM, CRC
from time import sleep, time
import argparse

LOG = logging.getLogger(__name__)


def upload_firmware(dev, firmware_path):
    sdev = serial.Serial(port=dev, baudrate=115200, bytesize=8, parity='N',stopbits=1, timeout=None, xonxoff=0, rtscts=0)
    LOG.info("Uploading firmware to device %s", sdev.port)

    LOG.debug("Looking for the bootloader menu")
    sdev.write(b'i')
    line = sdev.readline()
    sleep(1.0)
    while sdev.inWaiting():
        line = sdev.readline()
        if b'BOOTLOADER' in line:
            LOG.info(line)
            break
        else:
            raise RuntimeError("Couldn't find bootloader menu")

    def getc(size, timeout=1):
        return sdev.read(size)

    def putc(data, timeout=1):
        sdev.write(data)

    LOG.debug("Sending firmware via XMODEM")
    with open(firmware_path, 'rb') as firmware:
        sdev.write(b'u')

        LOG.debug("Waiting for CRC character")
        start = time()
        while time() - start < 3.0:
            char = sdev.read(1)
            if char == CRC:
                break
        else:
            raise RuntimeError("Timeout waiting for CRC character")

        LOG.debug("Starting XMODEM transfer.")
        upload_success = XMODEM(getc, putc).send(firmware, retry=16, timeout=60*4, quiet=0)

        if upload_success:
            LOG.debug("Firmware uploaded to %s", sdev.port)
        else:
            raise RuntimeError("Error in XMODEM transfer")

        # Reset module into firmware
        LOG.info("New firmware uploaded and verified by module %s", sdev.port)
        sdev.write(b'r')


def main():
    parser = argparse.ArgumentParser(description=__doc__)
    parser.add_argument('firmware', help='path to the firmware bin to load')
    parser.add_argument('--device', help='Path of the device to program')
    args = parser.parse_args()

    if args.device and args.firmware:
        upload_firmware(args.device, args.firmware);


if __name__ == '__main__':
    logging.basicConfig(level=logging.DEBUG)
    main()

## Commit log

2017-01-20 initial schematics
    [draw.kicad_pcb, draw.sch, mcu.sch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]
2017-01-20 split into 2 sheets + drc
    [mcu.sch, measure.sch]
2017-01-22 added pullups for I2C and alert
    [draw.sch, mcu.sch, measure.sch]
2017-01-22 added moar decoulping caps
    [mcu.sch, measure.sch]
2017-01-22 added footprint for switch
    [measure.sch]
2017-01-30 first layout
    [mcu.sch, measure.sch]
2017-02-05 second layout
    [draw.kicad_pcb]
2017-02-05 third layout, passes drc
    [draw.kicad_pcb]
2017-02-05 added gerbers
    [draw-B.Cu.gbr, draw-B.Mask.gbr, draw-B.SilkS.gbr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]
2017-02-07 moved things around and layout pdf
    [draw-B.Cu.gbr, draw-B.Mask.gbr, draw-B.SilkS.gbr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]
2017-02-07 added logo and url silkscreen
    [draw.kicad_pcb]
2017-02-12 updated gerbers
    [draw-B.Cu.gbr, draw-B.Mask.gbr, draw-B.SilkS.gbr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]
2017-02-22 added bom tracking
2017-03-14 fixed the issue with the power pads for INA260
    [draw.kicad_pcb]
2017-03-14 updated silkscreen bumped version
    [draw.kicad_pcb]
2017-03-31 fixed the footprint for button
    [draw.kicad_pcb]
2017-05-07 basic working firmware with i2c output over uart
2017-05-14 added retargetserial sample
2019-03-23 moving to kicad5
2019-03-23 updated to work in kicad 5.1
    [draw-2019-03-23-14-43-36.sch, draw.kicad_pcb, draw.sch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]
2019-03-23 removing all the rescued parts
    [draw-2019-03-23-14-43-36.sch, mcu-2019-03-23-14-43-36.sch, measure-2019-03-23-14-43-36.sch]
2019-03-24 removed tomu samples
2019-07-27 moved to new firmware from tomu-samples
2020-08-09 v2 schematic
2020-08-09 changed resistors to 4K7
    [draw.sch]
2020-08-15 added VBUS and GND Power headers
    [draw.sch]
2020-09-08 updating footprint assignment
    [draw.kicad_pcb, draw.sch, draw_old.kicad_pcb]

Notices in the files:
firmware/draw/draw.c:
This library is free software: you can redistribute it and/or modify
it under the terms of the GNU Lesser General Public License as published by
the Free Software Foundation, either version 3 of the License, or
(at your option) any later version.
